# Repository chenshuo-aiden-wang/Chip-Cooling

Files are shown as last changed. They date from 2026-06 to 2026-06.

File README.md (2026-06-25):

# K-16 Cold Plate

A cold plate design study on the ASME K-16 / IEEE ITherm Student Cold Plate Design Competition
problem. A fin plate is designed for a non uniform power map and evaluated in Ansys Icepak and
Fluent against the competition Figure of Merit.

See [`SPEC.md`](SPEC.md) for the problem data and the Figure of Merit.

## Structure

```
SPEC.md       problem data and Figure of Merit
model/        analytical model, used as a cross check on the CFD
cfd/          Icepak and Fluent cases                (coming)
report/       write up                               (coming)
resources/    competition guidance and CAD
```

## Tools

Ansys Icepak and Fluent for the CFD. Python (`model/`) for an analytical cross check.

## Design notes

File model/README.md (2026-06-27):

# Model

All analysis for the K-16 cold plate problem. The workflow runs hand calc, then Icepak, then
Fluent, with the geometry in `cad/` and the outputs in `results/`.

## Folders

| Folder | What it holds |
|---|---|
| `cad/` | Geometry. The original competition STEP, the cleaned STEP, SpaceClaim files, the extracted fluid volume, and the fin plate designs. |
| `handcalc/` | Python analytical estimate of thermal resistance and pressure drop, a sanity check on the CFD. `functions.py`, `spec.py`, `HANDCALC.md`. |
| `icepak/` | Icepak project files. Design exploration: run several fin architectures and rank them by Figure of Merit. |
| `fluent/` | Fluent cases and results. High fidelity validation of the chosen design. |
| `results/` | Figure of Merit values, comparison tables, and the figures for the write up. |

## Workflow

1. `cad`: clean the geometry and extract the fluid volume.
2. `handcalc`: get a ballpark resistance and pressure drop to check the CFD against.
3. `icepak`: simulate the baseline and the candidate fin designs, compute the Figure of Merit, down select.
4. `fluent`: validate the chosen design at high fidelity.
5. `results`: collect the Figure of Merit numbers and the figures.

The problem data and the Figure of Merit are in `../SPEC.md`.

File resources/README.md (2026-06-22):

# Resources

Reference material for the project (kept, not auto-generated).

- **`ansys/`** — Ansys tutorial files, example models, exported figures, and any Icepak /
  Fluent learning material. *(Note: large solver output, locks, and temp files are
  git-ignored — keep your `.aedt` models, not the results dumps.)*
- **`references/`** — papers, datasheets, and PDFs (e.g., the Icepak Cold Plate tutorial).

See `_private/05_LITERATURE.md` (local) for the full reading list and links.

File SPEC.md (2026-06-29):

# Spec: K-16 Cold Plate

Baseline data for the design problem. Source: ASME K-16 / IEEE ITherm competition guidance
(`resources/`).

## Operating conditions

| Parameter | Value |
|---|---|
| Flow rate | 1.2 L/min |
| Inlet temperature | 30 C |
| Ambient temperature | 20 C |

## Power map (total 800 W)

Three heater rows tiling the 32.2 x 25.8 mm die (830 mm2).

| Zone | Size | Power | Flux |
|---|---|---|---|
| H | 8.6 x 32.2 mm | 400 W | 1.44 W/mm2 |
| BG1 | 8.6 x 32.2 mm | 200 W | 0.72 W/mm2 |
| BG2 | 8.6 x 32.2 mm | 200 W | 0.72 W/mm2 |

Scoring uses the maximum temperature within each zone.

## Parts and materials

| Part | Dimensions | Material | Notes |
|---|---|---|---|
| Fin plate | 36 x 29 x 2 mm | Copper (AM), k 380 W/m K | design space |
| Baseplate | 53 x 46 x 2 mm | Copper (AM), k 380 W/m K | fixed geometry |
| Manifold | per CAD | not specified | fixed geometry |
| Gasket | 2 mm thick | Silicone | above fin plate; k not given |
| Coolant | n/a | PG-25 | properties not given |
| Die | 32.2 x 25.8 mm | Silicon | heat source; TTC-1002 chip array, see note |
| Substrate | 81 x 75 mm | not specified | TTV-4103 board |
| Tube, inlet and outlet | 3/8 in ID | not specified | |
| TIM, TTV to plate | interface | 0.03 cm2 K/W | area specific contact resistance |

Notes:
- Copper k 380 W/m K is the as printed effective value. Density and cp are not in the guidance; take them from the Icepak copper library.
- Page 1 prints the coolant as "Polypropylene Glycol 25%". PG-25 conventionally denotes propylene glycol 25%. Confirm with the organizers.
- PG-25 fluid properties (density, cp, k, viscosity) are not in the guidance; source from a coolant datasheet or ASHRAE / Melinder glycol tables.
- The die is silicon: the TTV-4103 die is an array of TEA TTC-1002 thermal test chips (silicon, 2.5 mm unit cells). This is from the TTV / TTC-1002 documentation, not the K-16 guidance. TEA does not publish a conductivity; use standard silicon (k about 130 W/m K at operating temperature). Take the die thickness from the CAD.

## Manufacturing constraints

| Item | Value |
|---|---|
| Surface roughness | 1.5 um |
| Min feature | 0.10 mm |
| Max feature, X-Y | 0.50 mm |
| Max feature, Z | 3 mm |
| Voxel, X-Y | 33.33 um |
| Min layer, Z | 0.030 mm |
| Min overhang | 20 deg from XY plane |
| File format | STEP |

## Figure of Merit

```
FoM = 0.7 (R_b - R) / R_b + 0.3 (dP_b - dP) / dP_b
R   = max(T_chip - T_inlet) / q_total
dP  = inlet to outlet pressure drop across the manifold
```

Subscript b is the provided baseline fin plate, simulated the same way.

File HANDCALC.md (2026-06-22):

# Hand-Calc Package — GPU Cold-Plate Test Bench

**Rev:** 0.1 · **Date:** 2026-06-21 · Supports [`SPEC.md`](SPEC.md)

First-principles feasibility analysis behind the spec targets. Everything here is a
*hand estimate* to be refined by CFD (Icepak/Fluent) and measurement. Assumptions and
limitations are stated in §6 — read them; the numbers are only as good as those.

---

## 0. Givens & fluid properties

| Quantity | Symbol | Value |
|---|---|---|
| Heat load | `Q` | 500 W |
| Heated die area | `A` | 4 cm² = 4×10⁻⁴ m² |
| Coolant inlet temp | `T_in` | 30 °C |
| Junction limit | `T_j,max` | 85 °C |
| Design flow | `V̇` | 1.5 L/min = 2.5×10⁻⁵ m³/s |

Water properties (~35 °C): ρ = 994 kg/m³, cp = 4180 J/kg·K, k_w = 0.62 W/m·K,
μ = 7.2×10⁻⁴ Pa·s, Pr ≈ 4.8. Copper: k_cu = 400 W/m·K.

## 1. Heat flux
```
q'' = Q / A = 500 / 4 = 125 W/cm²   (1.25×10⁶ W/m²)
```
GPU-realistic localized flux. (For reference, real AI dies run ~50–125+ W/cm².)

## 2. Required total thermal resistance
```
R_total ≤ (T_j,max − T_in) / Q = (85 − 30) / 500 = 0.11 °C/W
```
**Everything from chip to coolant inlet must sum to ≤ 0.11 °C/W.**
(State-of-the-art DTC plates ≈ 0.02 °C/W, so 0.11 is a forgiving first target.)

## 3. Flow / caloric check
Coolant bulk temperature rise:
```
ṁ = ρ·V̇ = 994 × 2.5×10⁻⁵ = 0.0248 kg/s
ΔT_fluid = Q / (ṁ·cp) = 500 / (0.0248 × 4180) ≈ 4.8 °C
```
Caloric resistance (referenced to inlet, using mean fluid temp):
```
R_caloric = 1 / (2·ṁ·cp) = 1 / (2 × 0.0248 × 4180) ≈ 0.005 °C/W
```
→ Coolant rises only ~5 °C; flow of 1.5 L/min is adequate and **not** the bottleneck. ✓

## 4. Resistance budget
```
R_total = R_TIM + R_spreading + R_convection + R_caloric ≤ 0.11 °C/W
```
| Term | Estimate | Basis |
|---|---|---|
| `R_TIM` | ~0.025 °C/W | `t/(k·A)` = 50 µm / (5 W/m·K × 4×10⁻⁴ m²) |
| `R_spreading` | ~0.015 °C/W | rough estimate; refine in CFD/FEA |
| `R_caloric` | ~0.005 °C/W | §3 |
| **`R_convection` (remaining)** | **≤ ~0.065 °C/W** | **what the channels must deliver** |

## 5. First-cut channel sizing — does R_conv ≤ 0.065 work?

`R_conv = 1/(h·A_wet)`, with `h = Nu·k_w/D_h`, `D_h = 2·w·h_c/(w+h_c)`,
`A_wet = 2·(w+h_c)·L·N`. Base width 20 mm, flow length L = 20 mm, laminar `Nu ≈ 4.5`.

| Design | Channels | w × h_c | D_h | Re | h (W/m²K) | A_wet | **R_conv** |
|---|---|---|---|---|---|---|---|
| **A — moderate** | 20 | 0.5 × 3 mm | 0.86 mm | ~990 (laminar) | ~3,240 | 28 cm² | **~0.11 °C/W** |
| **B — aggressive** | 25 | 0.4 × 5 mm | 0.74 mm | ~570 (laminar) | ~3,830 | 54 cm² | **~0.05 °C/W** |

**Verdict:**
- **Design A misses:** total ≈ 0.11 + 0.025 + 0.015 + 0.005 = **0.155 °C/W > 0.11**. ✗
- **Design B makes it (ideal):** total ≈ 0.05 + 0.045 = **~0.095 °C/W < 0.11**. ✓
  - *But* with **fin efficiency** (tall 5 mm × 0.4 mm copper fins, η ≈ 0.73), `R_conv` rises
    to ~0.067 → total ~0.11 °C/W → **marginal**.

## 6. Conclusions, assumptions & limitations

**Conclusion:** The 0.11 °C/W target is **feasible but tight** — it requires *aggressive
microchannels* (fine, tall). A naive/moderate channel design **fails** the spec. This is
exactly why CFD design + iteration is needed, and it tells you where to spend effort:
maximizing channel surface area and `h` while watching fin efficiency and pressure drop.

**Key assumptions (refine these):**
- Laminar fully-developed `Nu ≈ 4.5` (rectangular duct, const flux) — real entrance effects
  raise `h`; turbulence (higher flow) raises it more.
- Ignored **fin efficiency** in the table (noted separately for Design B) — CFD captures it.
- `R_TIM`, `R_spreading` are estimates — replace with datasheet + CFD/FEA values.
- Uniform heat flux assumed — the **hotspot** case (non-uniform) is harder; model later.
- Pressure drop / pumping power **not yet computed** — add next (finer channels cost ΔP).

**Next:** turn this into a Python tool (`model/`) so geometry → (°C/W, ΔP, pumping power)
is instant, then validate against Icepak/Fluent.

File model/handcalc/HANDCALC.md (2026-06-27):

# Hand calc method

A first cut estimate of cold plate thermal resistance and pressure drop for the K-16 problem,
used to sanity check the CFD before trusting it. Implemented in `functions.py`; inputs in
`spec.py`. Run: `python spec.py`.

## Method

For a representative parallel channel fin geometry:

1. Flow. The volumetric flow split across the channels gives the channel velocity, the
   hydraulic diameter, and the Reynolds number.
2. Convection. A developing flow Nusselt number (Hausen for laminar, Dittus Boelter for
   turbulent) gives the heat transfer coefficient h.
3. Fins. The channel side walls are treated as straight fins; fin efficiency reduces the
   effective wetted area.
4. Spreading. A Yovanovich spreading resistance for the die conducting into the fin plate
   (Lee, Yovanovich 1995); it reduces to 1D base conduction when the die and plate areas match.
5. Resistance stack:
   `R_total = R_conv + R_tim + R_spread + R_caloric`, where `R_conv = 1/(h A_eff)`, `R_tim` is
   the TIM area resistance divided by die area, and `R_caloric` is coolant bulk heating.
6. Chip temperature = inlet temperature + total power times `R_total`.
7. Pressure drop from the friction factor and the dynamic pressure; pumping power = dP times flow.
8. Figure of Merit, `0.7 (R_b - R)/R_b + 0.3 (dP_b - dP)/dP_b`, against the baseline fin plate. If
   `R_BASELINE` and `DP_BASELINE` are set from the baseline CFD, those are used. Otherwise the same
   hand calc is run on a simple straight-fin baseline (`BASELINE_*` in `spec.py`) to give a rough
   FoM. Both sides use the same method, so the systematic errors partly cancel in the ratio, but the
   number is only as good as the assumed baseline and uses average rather than peak resistance.

The power map is listed as three heater rows (H, BG1, BG2) tiling the die; the guidance gives the
sizes and powers but not the areas, so they are computed and cross checked against the die area and
the 800 W total. The stack itself still applies the total power uniformly.

## Inputs

All in `spec.py`, each labeled `[K-16]` fixed by the guidance, `[DESIGN]` your variable, or
`[ASSUME]` to refine. Key K-16 values: PG-25 coolant, 1.2 L/min, 30 C inlet, 800 W total,
TIM 0.03 cm2 K/W, copper k 380, die 32.2 x 25.8 mm.

## Assumptions and limits

- Uniform parallel channels. The real manifold flow distribution is ignored.
- Total power applied uniformly. The hotspot driven peak, the real R_th,max, is higher, and
  only CFD resolves it.
- Yovanovich spreading from the die into the plate; reduces to 1D conduction when the areas match.
- PG-25 properties from ASHRAE / Melinder glycol tables at ~30 C; verify on the coolant datasheet.

This brackets the CFD. It does not replace it.

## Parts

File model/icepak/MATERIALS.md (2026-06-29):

# Icepak materials for the K-16 cold plate

Material properties for the Icepak case. Values are from the competition guidance where stated,
otherwise from standard references (noted per row). See `../../SPEC.md` for the parts list.

Copper, silicon, FR-4, air, and water ship in the Icepak library; pick them and set copper k to
380. PG-25 is not in the library; add it.

## Assign these (in the heat path)

| Material | Part | k [W/m K] | density [kg/m3] | cp [J/kg K] | viscosity [Pa s] | Source |
|---|---|---|---|---|---|---|
| Copper (AM) | fin plate, baseplate | 380 | 8960 | 385 | n/a | k from guidance; density and cp standard copper |
| Silicon | die | 130 | 2330 | 712 | n/a | die is TTC-1002 silicon chips; k standard silicon |
| PG-25 | coolant | 0.48 | 1016 | 3970 | 2.1e-3 | ASHRAE / Melinder at 30 C |

PG-25 also takes a thermal expansion coefficient beta 3.9e-4 1/K (for buoyancy, negligible in this
pumped flow). Thermal diffusivity 1.19e-7 m2/s and molar mass 22.3 g/mol are derived or optional:
diffusivity is k / (rho cp), and molar mass is used only for the ideal gas law, not a liquid.

## Not in the heat path

| Item | Handling |
|---|---|
| TIM, TTV to plate | contact resistance 3.0e-6 m2 K/W (0.03 cm2 K/W), not a material |
| Manifold, tubes | adiabatic walls, no material needed; if a solid is required, plastic k ~0.2 |
| O-rings | exclude; if kept, elastomer k ~0.2 |
| Substrate | adiabatic or excluded, all power into the cold plate |
| Gasket | Silicone, k 0.2, density 1150, cp 1100 if modeled |

## Notes

- Copper k 380 is the as printed effective value, below bulk copper. Density and cp are standard.
- Silicon k is temperature dependent, about 148 at room temperature and near 130 at the operating
  temperature. The die thickness comes from the CAD.
- PG-25 properties are at ~30 C and vary with temperature. Confirm the 25 percent basis (mass or
  volume) and propylene glycol, not polypropylene glycol, with the organizers.
- Silicone, manifold, and O-ring values are assumed standard values; these parts sit outside the
  heat path, so the exact value has little effect.

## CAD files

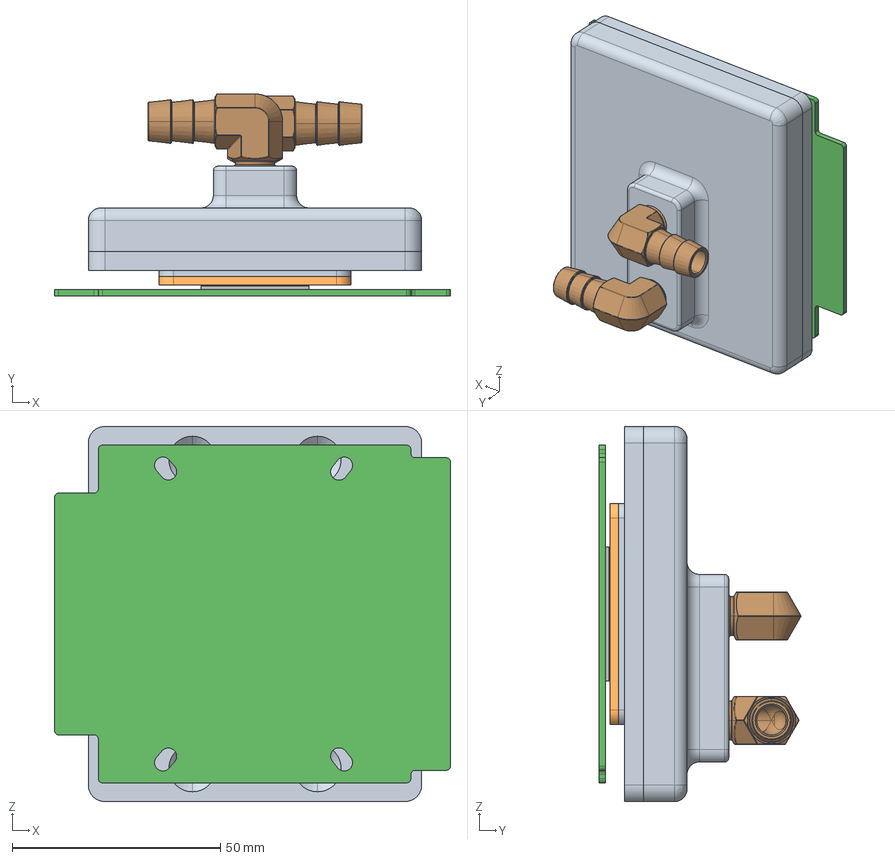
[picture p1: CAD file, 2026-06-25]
model/cad/Assembly_Itherm_2026_original.stp
95.0 x 48.5 x 90.0 mm
TTV PCB
TTV Die
TIM
O-Ring 1
Baseplate
O-Ring 2
Manifold gasket x 2
Manifold
Fitting x 2
Fin Plate

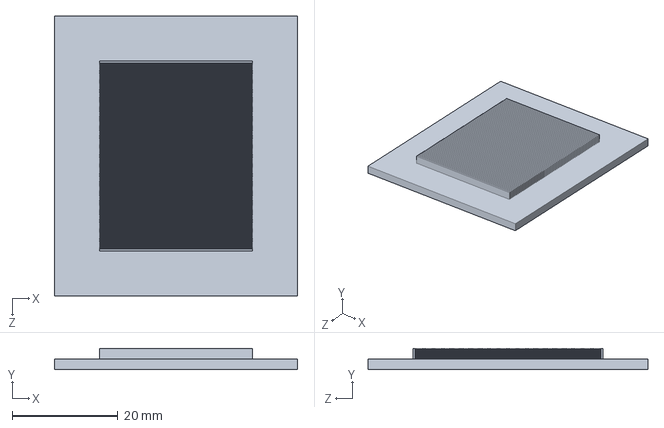
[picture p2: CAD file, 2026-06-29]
model/cad/Itherm_cleanup/part8bodies.SLDPRT
46.0 x 4.00 x 53.0 mm

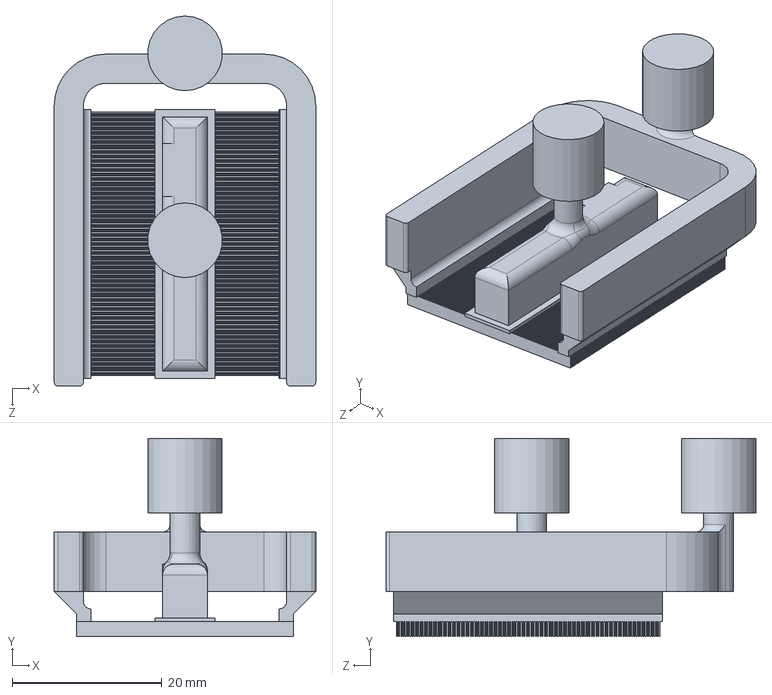
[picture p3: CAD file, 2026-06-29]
model/cad/Itherm_cleanup/part9bodies.SLDPRT
35.0 x 26.5 x 49.5 mm

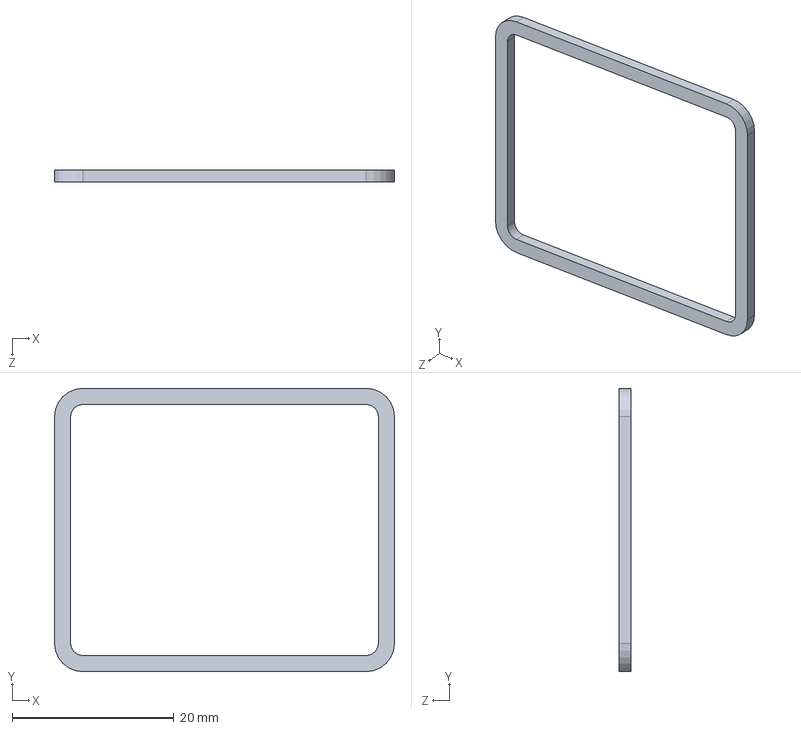
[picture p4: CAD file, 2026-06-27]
model/cad/Itherm_cleanup/part3bodies.SLDPRT
42.0 x 35.0 x 1.50 mm

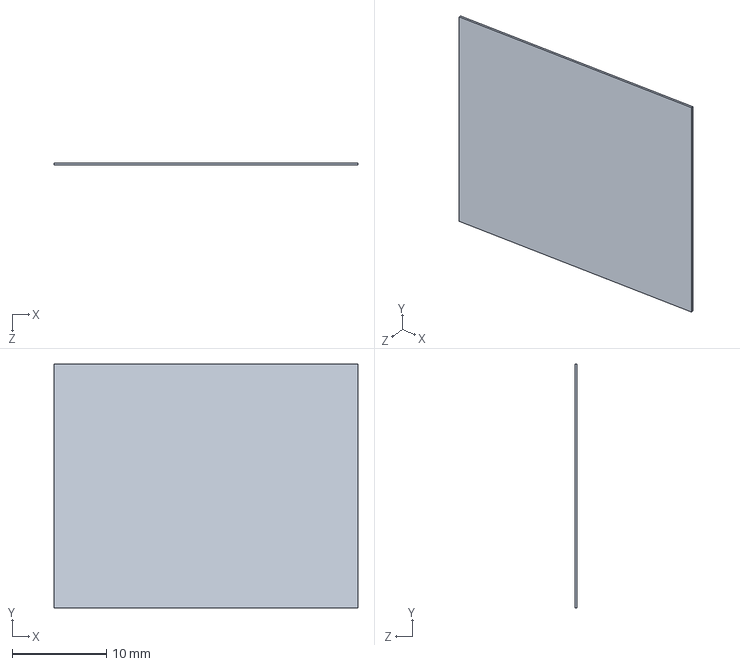
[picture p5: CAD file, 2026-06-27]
model/cad/Itherm_cleanup/part2bodies.SLDPRT
32.2 x 25.8 x 0.25 mm

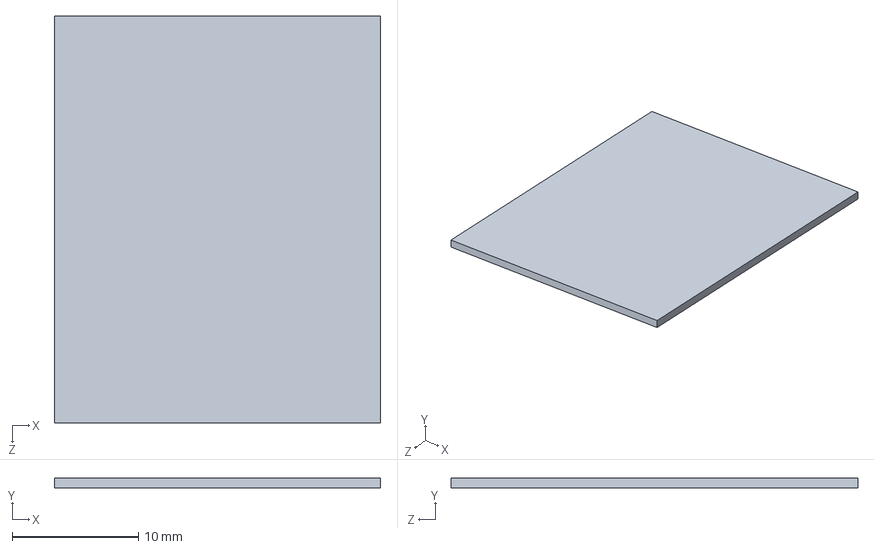
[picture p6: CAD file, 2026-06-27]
model/cad/Itherm_cleanup/part1bodies.SLDPRT
25.8 x 0.8 x 32.2 mm

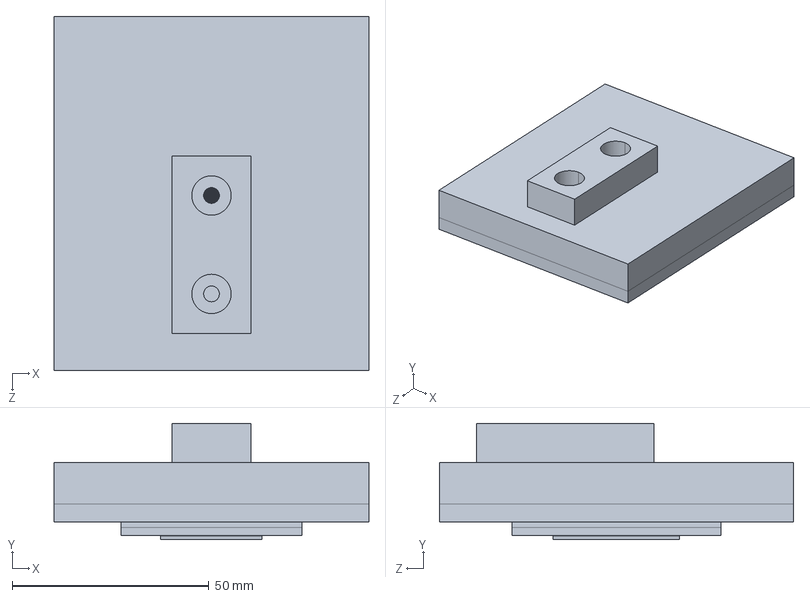
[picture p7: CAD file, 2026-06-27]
model/cad/Itherm_cleanup/Assem2.STEP
80.0 x 29.5 x 90.0 mm
part1bodies
part2bodies
part3bodies
part4bodies
part5bodies
part6bodies x 2
part7bodies
part8bodies

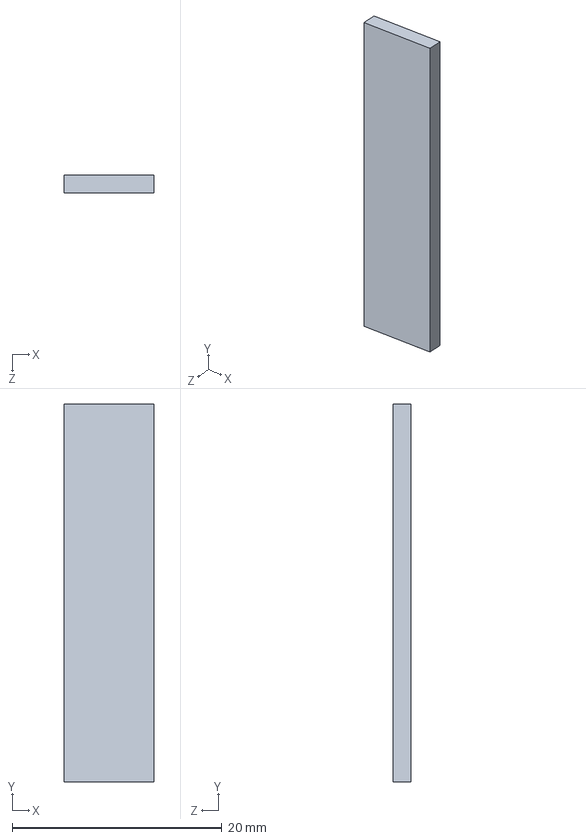
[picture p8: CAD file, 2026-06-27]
model/cad/Itherm_cleanup/part6bodies.SLDPRT
8.60 x 36.0 x 1.70 mm

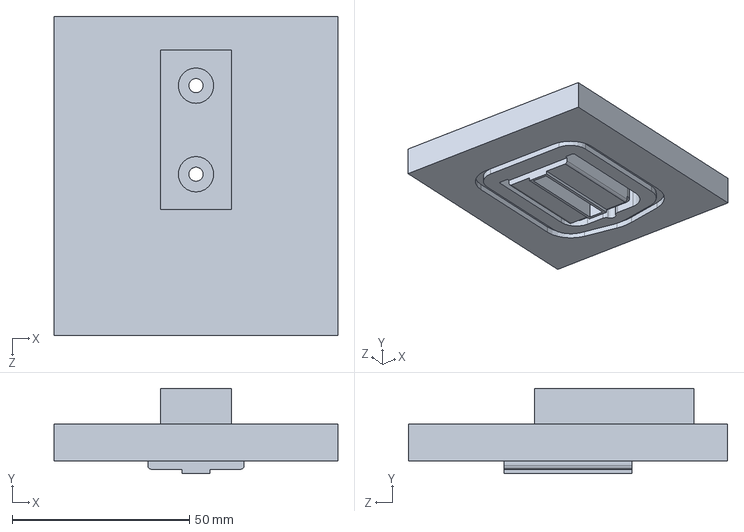
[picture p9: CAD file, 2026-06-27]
model/cad/Itherm_cleanup/part7bodies.SLDPRT
80.0 x 24.0 x 90.0 mm

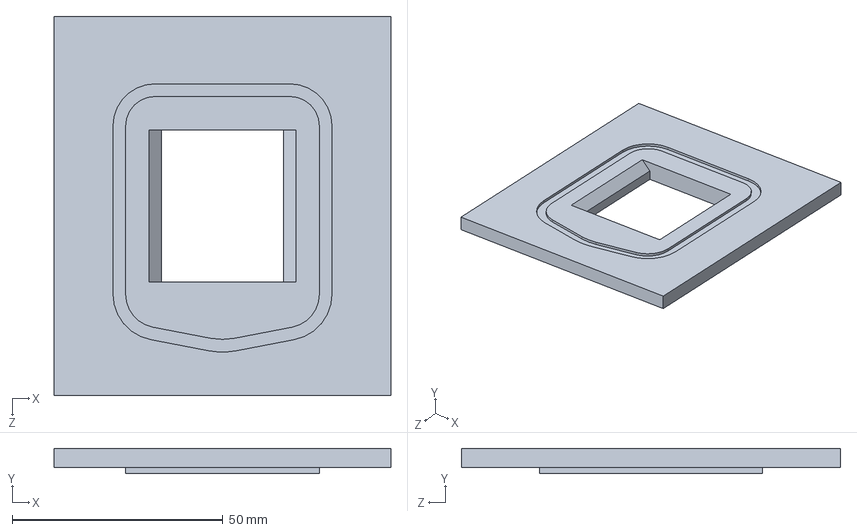
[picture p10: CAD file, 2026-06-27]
model/cad/Itherm_cleanup/part4bodies.SLDPRT
80.0 x 6.00 x 90.0 mm

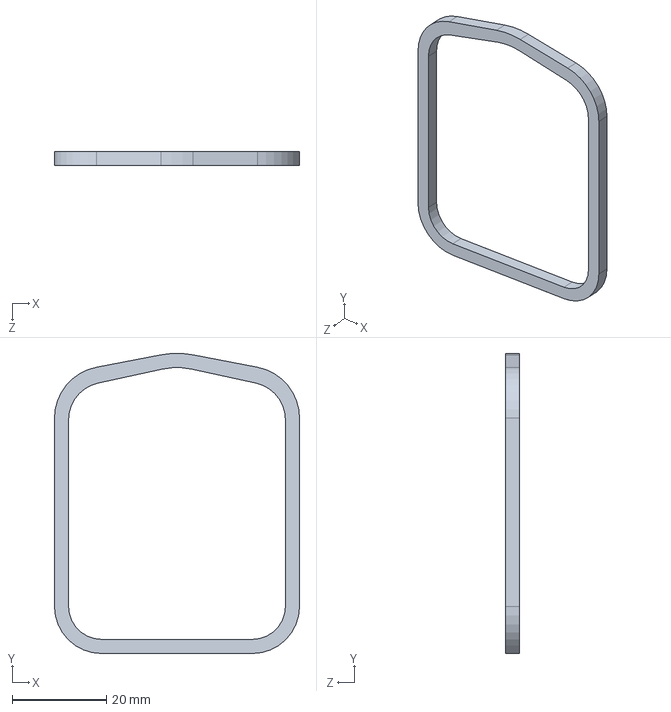
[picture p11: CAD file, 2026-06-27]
model/cad/Itherm_cleanup/part5bodies.SLDPRT
52.0 x 63.6 x 3.00 mm

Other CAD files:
model/cad/Itherm_cleanup/Assem2.SLDASM

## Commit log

2026-06-25 refine model
    [Assembly_Itherm_2026.stp]
2026-06-27 model update
    [Assem2.SLDASM, Assem2.STEP, Assembly_Itherm_2026_original.stp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]
2026-06-29 update: model, spec-material
    [Assem2.SLDASM, Assembly_Itherm_Cleanup_v.1.0.STEP, materials.csv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]
2026-06-29 update: spec-material
    [materials.csv]
